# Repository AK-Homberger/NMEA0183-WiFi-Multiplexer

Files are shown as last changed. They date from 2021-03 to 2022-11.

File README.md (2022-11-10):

# NMEA0183 WiFi Multiplexer with ESP8266 (D1 Mini)

# Caution! 
# ----------------------------
This is an updated version (0.2) with pins changed from D7/D8 to D6/D7 to avoid boot problems (see Issues).
If you ordered already a version 1.0 PCB, then just cut the connection to D8 (e.g. with a knife) and solder a wire to D6 pin on D1 Mini. The updated software (version 0.2) will work then. But with changed serial line numbers from #1 to #2 and vice versa.
# ----------------------------

The project reads NMEA0183 messages from two serial (RS232) inputs and forwards multiplexed messages to USB-Serial and WLAN as UDP broadcast.

The multiplexer is powered either from USB connection or with 12 Volt via DC-DC converter.
ESP8266 is using Software Serial on ports D6 and D7.

Main purpose is to provide GPS and AIS information wirelessly to a tablet/smartphone for navigation.
Works with Navionics app (configure UDP connection with Host: x.y.z.255 and Port: 4444).

There is also a [software version](https://github.com/AK-Homberger/NMEA0183-WiFi-Multiplexer/tree/main/NMEA083-Parser-WiFi-Multiplexer) that is parsing the messages and can suppress certain messages. This version needs this additional NMEA0183 libray: https://github.com/ttlappalainen/NMEA0183

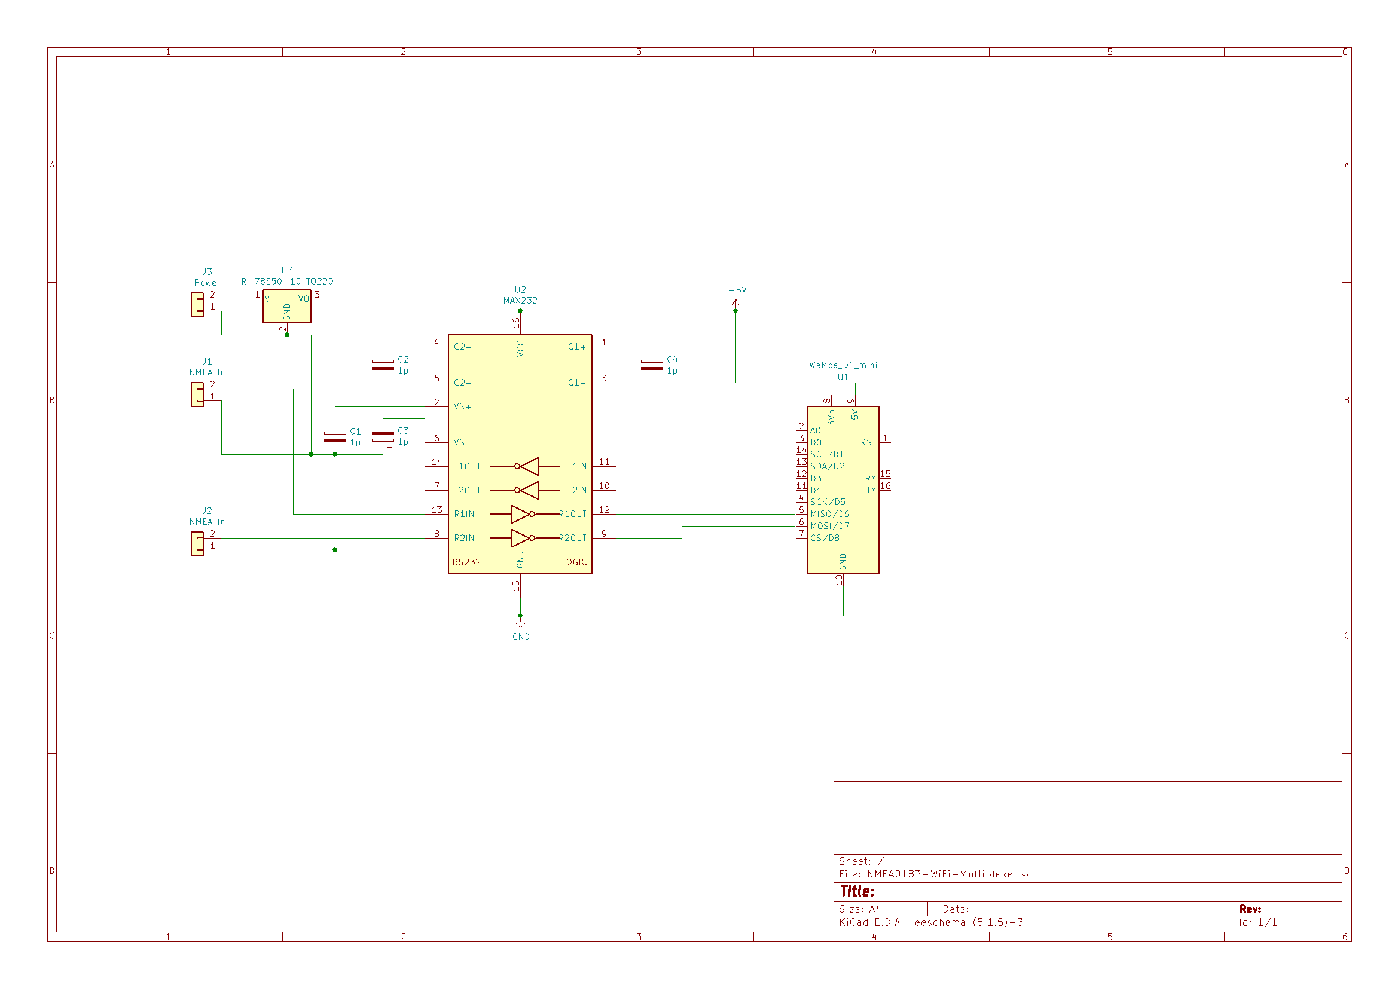
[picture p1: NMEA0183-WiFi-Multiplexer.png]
Schematics


Just change the settings in the [programm](https://github.com/AK-Homberger/NMEA0183-WiFi-Multiplexer/blob/main/NMEA083-WiFi-Multiplexer/NMEA083-WiFi-Multiplexer.ino) according to your needs:

```
// Change these values only
// ------------------------------------------------------------------------
#define AP 0             // Set to 1 to act as Access Point, 0 as client 

const char *ssid      = "ssid";           // Set WLAN name
const char *password  = "password";      // Set password

const char *udpAddress = "192.168.4.255"; // Set network address for broadcast
const int udpPort = 4444;                 // UDP port

#define BaudRate1 4800   // Baud rate for serial#1
#define BaudRate2 38400  // Baud rate for serial#2

// -------------------------------------------------------------------------

```

KiCad files are available to change/extend and to create a [PCB](https://github.com/AK-Homberger/NMEA0183-WiFi-Multiplexer/blob/main/KiCadNMEA0183-WiFi-Multiplexer/PCB.pdf).

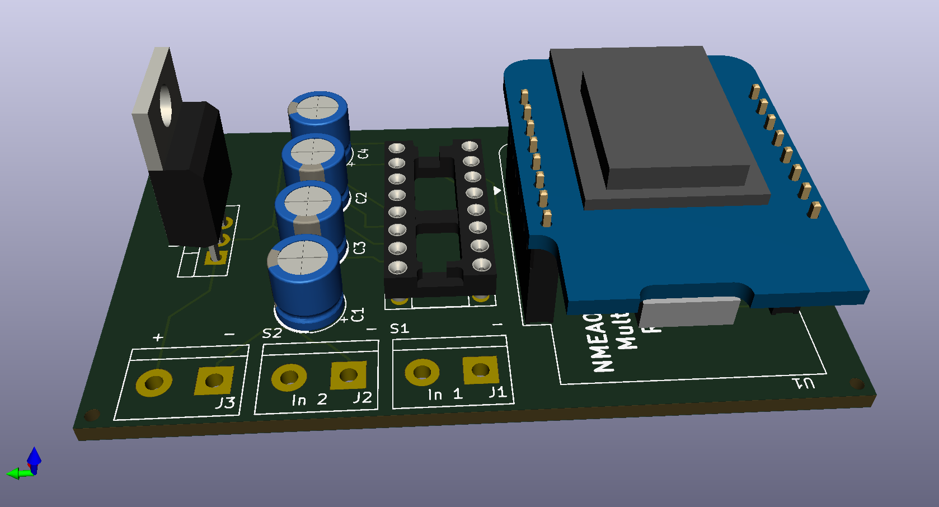
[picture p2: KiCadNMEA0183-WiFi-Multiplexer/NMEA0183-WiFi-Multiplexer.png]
Board


## Parts

- U1: [ESP8266 (D1Mini)](https://www.reichelt.de/de/en/d1-mini-esp8266-v3-0-d1-mini-p253978.html?&nbc=1)
- U2: [Max232](https://www.reichelt.de/de/en/rs232-driver-dil-16-max-232-cpe-p11216.html?&nbc=1)
- C1-C4: 4* [Capacitor 1µF](https://www.reichelt.de/de/en/tantalum-capacitor-rm-2-5-1-0-f-35-v-tantal-1-0-35-p20330.html?&nbc=1)
- J1-J3: 3* [Connector](https://www.reichelt.de/de/en/2-pin-terminal-strip-spacing-5-08-akl-101-02-p36605.html?&nbc=1)
- U3: [DC-DC Converter](https://www.reichelt.de/de/en/dc-dc-converter-5-v-1-a-single-r-78e50-10-p177268.html?&nbc=1)
- [Board](https://aisler.net/p/EZUNBBJG) @Aisler.net

## Updates
- 10.11.2022 - Version 0.3: Corrected line end handling to avaid duplication of messages sent (see Issues).
- 01.10.2021 - Version 0.2: Changed pins from D/D8 to D6/D7 to avoid boot problems (see Issues).
- 06.03.2021 - Version 0.1: Initial version

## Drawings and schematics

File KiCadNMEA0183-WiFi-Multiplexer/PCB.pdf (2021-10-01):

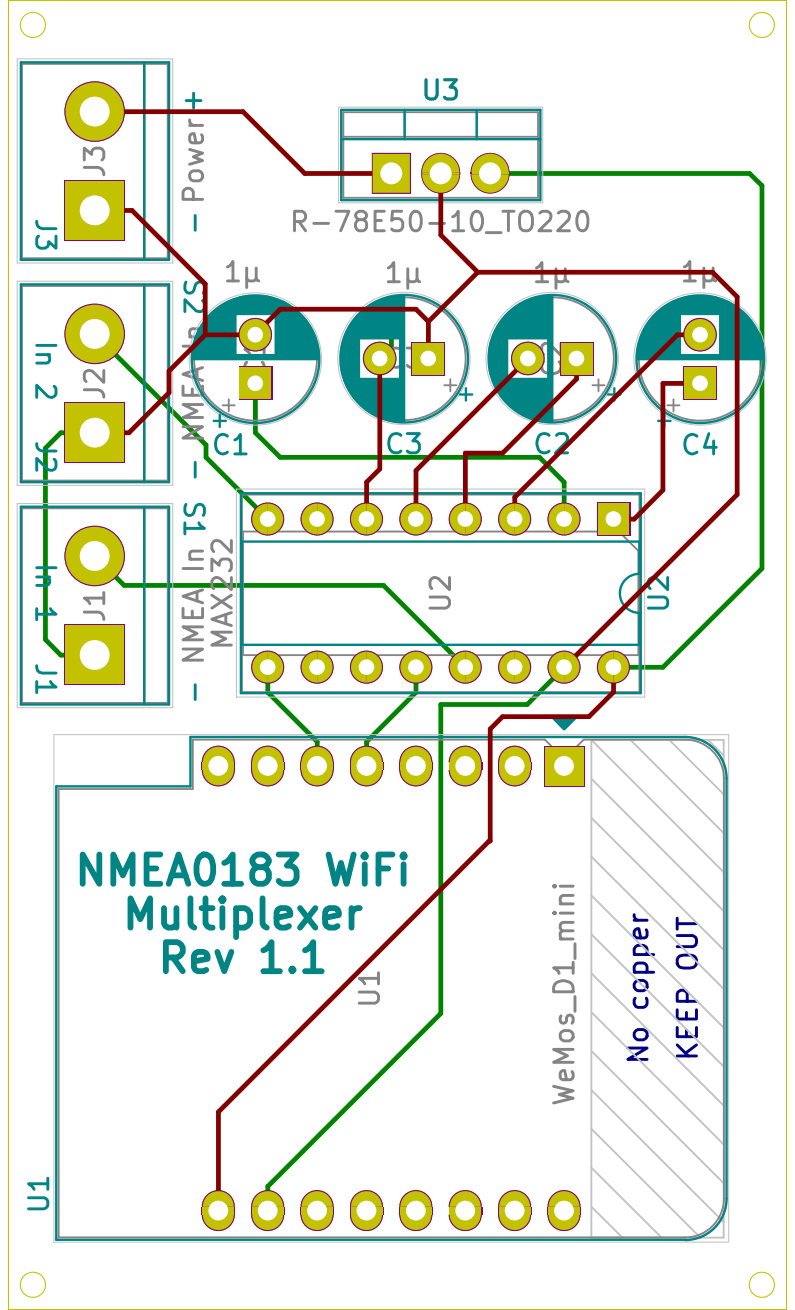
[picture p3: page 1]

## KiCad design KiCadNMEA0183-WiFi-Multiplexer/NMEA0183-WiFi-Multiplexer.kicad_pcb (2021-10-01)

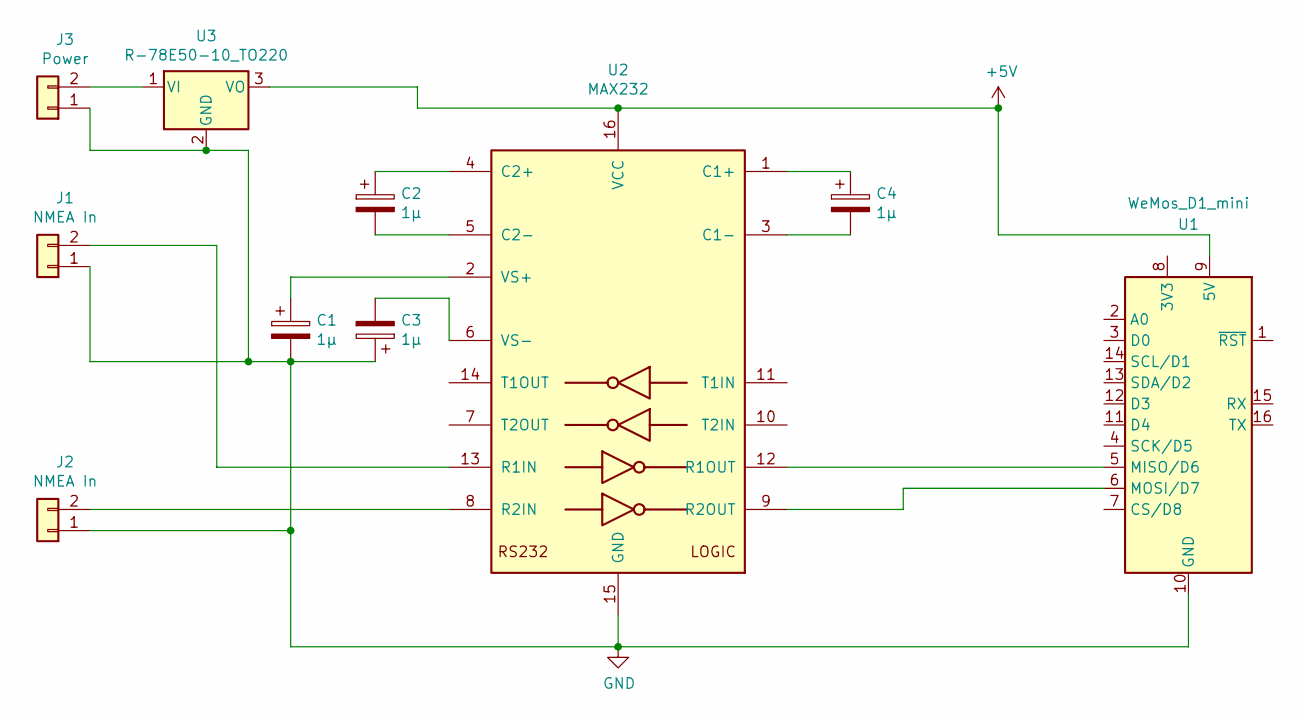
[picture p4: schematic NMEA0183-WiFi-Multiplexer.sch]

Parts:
C1, C2, C3, C4: 1µ; CP_Radial_D6.3mm_P2.50mm
J1, J2: NMEA In; TerminalBlock_bornier-2_P5.08mm
J3: Power; TerminalBlock_bornier-2_P5.08mm
U1: WeMos_D1_mini; WEMOS_D1_mini_light
U2: MAX232; DIP-16_W7.62mm_Socket
U3: R-78E50-10_TO220; TO-220-3_Vertical

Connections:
+5V: U1.9 (5V), U2.16 (VCC), U3.3 (VO)
GND: C1.2, C3.1, J1.1, J2.1, J3.1, U1.10 (GND), U2.15 (GND), U3.2 (GND)
unnamed: C1.1, U2.2 (VS+)
unnamed: C2.1, U2.4 (C2+)
unnamed: C2.2, U2.5 (C2-)
unnamed: C3.2, U2.6 (VS-)
unnamed: C4.1, U2.1 (C1+)
unnamed: C4.2, U2.3 (C1-)
unnamed: J1.2, U2.13 (R1IN)
unnamed: J2.2, U2.8 (R2IN)
unnamed: J3.2, U3.1 (VI)
unnamed: U1.5 (MISO/D6), U2.12 (R1OUT)
unnamed: U1.6 (MOSI/D7), U2.9 (R2OUT)

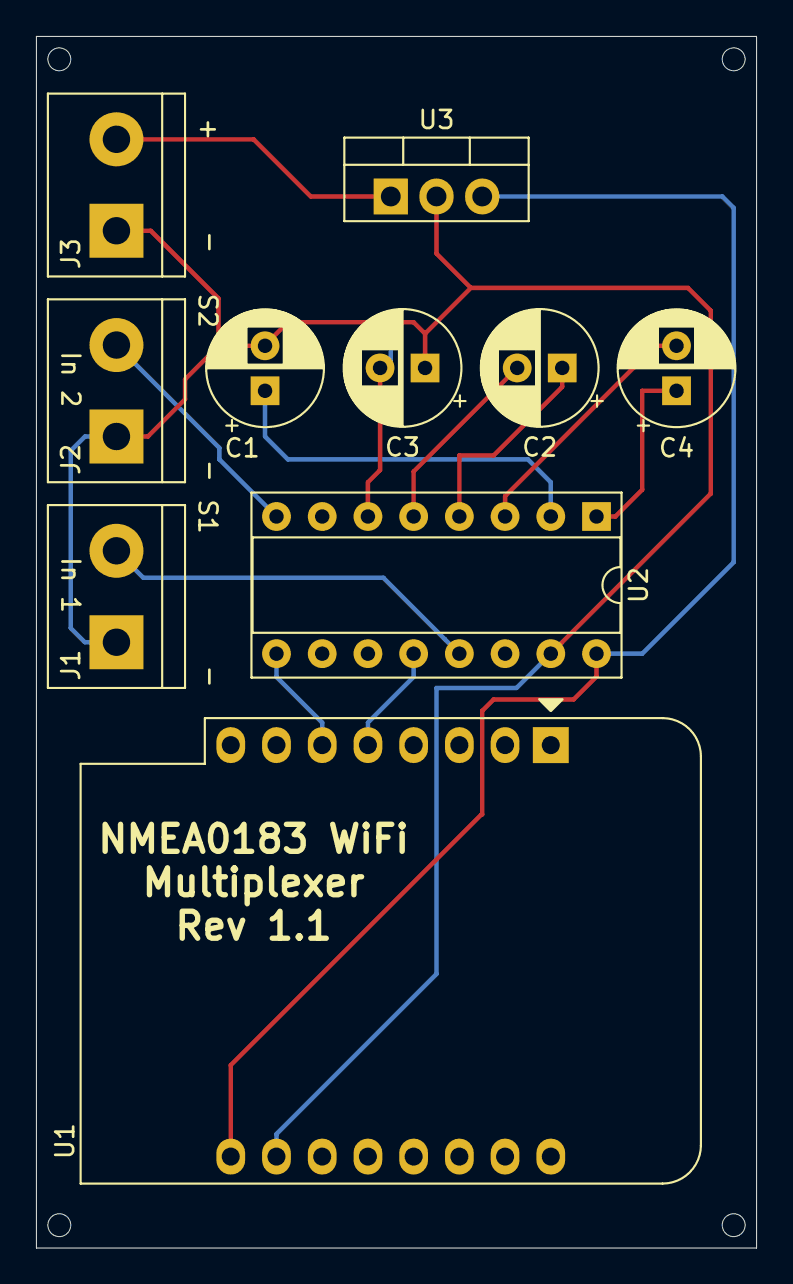
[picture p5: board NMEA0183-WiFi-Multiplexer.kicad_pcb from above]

Board: 2 copper layers, 40.0 x 67.3 mm, 10 parts (0 on the bottom side), 13 nets.

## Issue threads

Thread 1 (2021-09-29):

D8 sets boot loader into programming mode

hinnerkweiler, 2021-09-29:
Hi,

I just finished reconstructing this. However, after some testing I only get it to work when I leave D8 physically disconnected. The Levelshifter seems to send HIGH as soon as the PCB receives power and causes the booting ESP to head straight into Programming mode. Console says: "waiting for host", and that's forever.

I found this for a possible reason:
```
Bootloader Modes

The bootloader can go into a number of modes depending on the state of GPIOs 0, 2 and 15. The two useful modes are the UART download mode (for flashing new firmware) and the flash startup mode (which boots from flash).
						GPIO0(D3) | GPIO2(D4) | GPIO15(D8)
UART Download Mode (Programming)			0 	1 	0
Flash Startup (Normal)					1 	1 	0
SD-Card Boot						0 	0 	1
```

Did you manage to work around this to get the 2nd port activated?

Apparently it seems not to happen using a D1-Mini-Pro (I have none at hand to verify) However on regular D1-Mini (exactly the one you liked to) others also have run into similar problems and reproduced the issue:
https://forum.fhem.de/index.php?topic=71059.0

Hinnerk

AK-Homberger, 2021-10-01:
Changes done.

hinnerkweiler, 2021-10-01:
Ah, sure, that is the simple solution, it worked, while testing everything without the level shifter... Just hoped for a better solution than cutting tracks on the PCBs and run a wire... Just had three boards delivered and found the issue putting everything together. :-/

AK-Homberger, 2021-10-02:
Hi Hinnerk,

Unfortunately, there is no better solution for the old PCBs. But cutting one wire would have been enough. Just cut D8 line and connect to D6. Then change the pin definitions in the code.

And: This is a free of charge DIY solution. This is not a cmmercial product with all testing done and warranty. And my ability to buy and test the full hardware with the PCB is limited.  But I'm happy to react on identified issues and do the corrections/improvements (as I did here).

The situation would be better if at least a few people would use the PayPal button for donations for new hard/software.
But so far only one person used this opportunity.

Regards,
Andreas

Closed 2021-10-01.

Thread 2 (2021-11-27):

Wi-Fi with nmea 0183 data.

AlksSAV, 2021-11-27:
Great device!
I have an echo sounder that can transmit nmea data over Wi Fi. I want to transmit this data to the Ardupilot autopilot.
Is it possible to make nmea 0183 received over Wi-Fi network mixed with the first RS232 and transmitted to the second RS232?
Or just received nmea 0183 via Wi-Fi transmitted over RS232.

AK-Homberger, 2021-11-28:
With the current PCB this is not directly possible. The serial lines are input only.
But with a few changes in hard and software this would be possible.

AlksSAV, 2021-11-29:
> With the current PCB this is not directly possible. The serial lines are input only.
>
> But with a few changes in hard and software this would be possible.

It would be great to get this opportunity. For device tests, you can do without a PCB. If possible, please do the software part.

AK-Homberger, 2021-11-29:
Currently I don't have the time to do this. But I would suggest that you try to do this by your own. Intead of reading from Serial you have to read from a TCP connection and write the message to Serial. Information on how to use TCP is available here: https://github.com/esp8266/Arduino/blob/master/libraries/ESP8266WiFi/examples/WiFiClient/WiFiClient.ino

Closed 2021-12-01.

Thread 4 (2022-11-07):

all nmea data is sent twice

maxnae, 2022-11-07:
Regardless of whether I switch off a softserial or not. all nmea data is sent twice. Can this be prevented?

AK-Homberger, 2022-11-07:
Try to commet out the second send code and check if its now sent only once.

/*
if (GetNMEA0183Message2() == true) {    // Get NMEA sentences from serial#2
    SendNMEA0183Message(buf2);    // Send to clients
  }
*/

And check that there is no shortcut between both serial RX lines.

maxnae, 2022-11-07:
Thanks.
I tried but unfortunately the result is the same. There is also no connection at D6 and D7.

$GPGSV,1,1,00*79
$GPGSV,1,1,00*79
$GLGSV,1,1,00*65
$GLGSV,1,1,00*65
$GNGLL,,,,,,V,N*7A
$GNGLL,,,,,,V,N*7A
$GNRMC,,V,,,,,,,,,,N*4D
$GNRMC,,V,,,,,,,,,,N*4D
$GNVTG,,,,,,,,,N*2E
$GNVTG,,,,,,,,,N*2E
$GNGGA,,,,,,0,00,99.99,,,,,,*56
$GNGGA,,,,,,0,00,99.99,,,,,,*56
$GNGSA,A,1,,,,,,,,,,,,,99.99,99.99,99.99*2E
$GNGSA,A,1,,,,,,,,,,,,,99.99,99.99,99.99*2E
$GNGSA,A,1,,,,,,,,,,,,,99.99,99.99,99.99*2E
$GNGSA,A,1,,,,,,,,,,,,,99.99,99.99,99.99*2E
$GPGSV,1,1,00*79
$GPGSV,1,1,00*79
$GLGSV,1,1,00*65
$GLGSV,1,1,00*65
$GNGLL,,,,,,V,N*7A
$GNGLL,,,,,,V,N*7A
is it maybe necessary to have a delay when reading softserial?
best regards max

maxnae, 2022-11-09:
Here is the output

68
13
$GNRMC,,V,,,,,,,,,,N*4D
10
$GNRMC,,V,,,,,,,,,,N*4D
36
71
78
86
84
71
44
44
44
44
44
44
44
44
44
78
42
50
69
13
$GNVTG,,,,,,,,,N*2E
10
$GNVTG,,,,,,,,,N*2E
36
71
78
71
71
65
44
44
44
44
44
44
48
44
48
48
44
57
57
46
57
57
44
44
44
44
44
44
42
53
54
13
$GNGGA,,,,,,0,00,99.99,,,,,,*56
10
$GNGGA,,,,,,0,00,99.99,,,,,,*56
36
71
78
71
83
65
44
65
44
49
44
44
44
44
44
44
44
44
44
44
44
44
44
57
57
46
57
57
44
57
57
46
57
57
44
57
57
46
57
57
42
50
69
13
$GNGSA,A,1,,,,,,,,,,,,,99.99,99.99,99.99*2E
10
$GNGSA,A,1,,,,,,,,,,,,,99.99,99.99,99.99*2E
36
71
78
71
83
65
44
65
best regards max

AK-Homberger, 2022-11-09:
Each caracter is received only once. That's OK so far. But then the buffer is sent twice. One time after CR (\n) and another time after receiving LF (\r). But that should not happen.

Please add these both lines in both receive functions:

if(ReceivedChars == 0 && (Char == '\r')) return false;
if(ReceivedChars == 0 && (Char == '\n')) return false;

before this code:

if ( (Char == '\n') || (Char == '\r') ) {
      ReceivedChars = 0;
      return true;
    }

Then it should work. It looks like my test system only sent one of the line end codes.

maxnae, 2022-11-09:
wonderful thanks worked.

one more question, how can I filter different gps sets so that they are not sent further or specify which ones to go through?

$GNVTG
$GPGSV
$GLGSV

best regards max

AK-Homberger, 2022-11-10:
You have to parse the NME0183 messages. You can try to use this library https://github.com/ttlappalainen/NMEA0183). But I think it's not directly working with SoftwareSerial.

maxnae, 2022-11-10:
Thank you very much, it looks like this is working perfectly.
I modified that a bit. looks awesome

  // Receive and check message codes to suppress
  if (NMEA0183_1.GetMessage(NMEA0183Msg)) {    // Get NMEA sentences from serial#1

    if (!((strcmp(NMEA0183Msg.Sender(), "GP") == 0) && NMEA0183Msg.IsMessageCode("GSV") ||
          (strcmp(NMEA0183Msg.Sender(), "GN") == 0) && NMEA0183Msg.IsMessageCode("VTG") ||
          (strcmp(NMEA0183Msg.Sender(), "GN") == 0) && NMEA0183Msg.IsMessageCode("GLL") ||
          (strcmp(NMEA0183Msg.Sender(), "GL") == 0) && NMEA0183Msg.IsMessageCode("GSV"))) {

      if (NMEA0183Msg.GetMessage(buf, MAX_NMEA0183_MESSAGE_SIZE - 1)) {
         SendNMEA0183Message(buf);    // Send to clients

best regards max

maxnae, 2022-11-11:
another question. I'm currently trying to transmit Softserial 1 filtered and Softserial2 as RAW (is not an NMEA sentence). Unfortunately I seem to have made a mistake here.
[NMEA083-Parser-WiFiMultiplexer_mod.txt](https://github.com/AK-Homberger/NMEA0183-WiFi-Multiplexer/files/9987979/NMEA083-Parser-WiFiMultiplexer_mod.txt)
best regards max

maxnae, 2022-11-18:
Thank you very much
best regards max

Closed 2022-11-18.

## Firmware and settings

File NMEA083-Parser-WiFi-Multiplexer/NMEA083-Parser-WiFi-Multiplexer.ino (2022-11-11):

/*
  This code is free software; you can redistribute it and/or
  modify it under the terms of the GNU Lesser General Public
  License as published by the Free Software Foundation; either
  version 2.1 of the License, or (at your option) any later version.
  This code is distributed in the hope that it will be useful,
  but WITHOUT ANY WARRANTY; without even the implied warranty of
  MERCHANTABILITY or FITNESS FOR A PARTICULAR PURPOSE.  See the GNU
  Lesser General Public License for more details.
  You should have received a copy of the GNU Lesser General Public
  License along with this library; if not, write to the Free Software
  Foundation, Inc., 51 Franklin St, Fifth Floor, Boston, MA  02110-1301  USA
*/
// NMEA0183 WiFi Multiplexer with NME0183 Message Parser to suppress or parse certain messages

// Reads NMEA0183 messages from serial connected to D6 and D7.
// Forwards multiplexed messages to USB-Serial and WLAN as UDP broadcast.
// Needs this NMEA0183 libray: https://github.com/ttlappalainen/NMEA0183

// Version 0.1, 10.11.2022, AK-Homberger

#include <ESP8266WiFi.h>
#include <WiFiUdp.h>
#include <SoftwareSerial.h>
#include <NMEA0183.h>
#include <NMEA0183Messages.h>

// Change these values only
// ------------------------------------------------------------------------
#define AP 1             // Set to 1 to act as Access Point, 0 as client 

const char *ssid      = "ssid";           // Set WLAN name
const char *password  = "password";       // Set password

const char *udpAddress = "192.168.4.255"; // Set network address for broadcast
const int udpPort = 4444;                 // UDP port

#define BaudRate1 4800   // Baud rate for serial#1
#define BaudRate2 4800   // Baud rate for serial#2

// -------------------------------------------------------------------------


#define MAX_NMEA0183_MESSAGE_SIZE 150
char buf[MAX_NMEA0183_MESSAGE_SIZE] = "";  // Buffer for message to send

// Create software serial objects
SoftwareSerial swSer1;
SoftwareSerial swSer2;

// NMEA streams for NMEA0183 receiving
tNMEA0183 NMEA0183_1;
tNMEA0183 NMEA0183_2;

boolean wifiConnected = false;

// Create UDP instance
WiFiUDP udp;


//*****************************************************************************
void setup(void) {

  Serial.begin(115200);

  // Initialise wifi connection
  wifiConnected = connectWifi();            // Connect to WLAN or start AP

  if (!wifiConnected) {
    Serial.println("Cannot connect to WiFi. Please check data. Reset the ESP now.");
    delay(3000);
    ESP.restart();
  }

  // Initialise software serial set baud rate to 4800 or 38400
  swSer1.begin(BaudRate1, SWSERIAL_8N1, D6, D6, false, 256);
  swSer1.enableIntTx(false);
  NMEA0183_1.SetMessageStream(&swSer1, 1);
  NMEA0183_1.Open();

  swSer2.begin(BaudRate2, SWSERIAL_8N1, D7, D7, false, 256);
  swSer2.enableIntTx(false);
  NMEA0183_2.SetMessageStream(&swSer2, 2);
  NMEA0183_2.Open();
}


//*****************************************************************************
// Connect to wifi or start AP – returns true if successful or false if not

boolean connectWifi() {
  boolean state = true;
  int i = 0;

  if (AP == 0) {
    WiFi.mode(WIFI_STA);
    WiFi.hostname("NMEA0183Multiplexer");
    WiFi.begin(ssid, password);
    Serial.println("Connecting to WiFi");
    // Wait for connection
    Serial.print("Connecting...");
    // Initialise wifi connection

    while (WiFi.status() != WL_CONNECTED) {
      delay(500);
      Serial.print(".");
      if (i > 10) {
        state = false; break;
      }
      i++;
    }
    Serial.println("");
    if (state) {
      Serial.print("Connected to ");
      Serial.println(ssid);
      Serial.print("IP address: ");
      Serial.println(WiFi.localIP());
    }
    else {
      Serial.println("Connection failed.");
    }
    return state;
  }  else {

    Serial.println("Start WLAN AP");         // WiFi Mode AP
    WiFi.mode(WIFI_AP);
    WiFi.softAP(ssid, password);
    delay(100);
    IPAddress IP = WiFi.softAPIP();
    Serial.println("");
    Serial.print("AP IP address: ");
    Serial.println(IP);
    return true;
  }
}


//*****************************************************************************
// Check WiFi connection

void Check_WiFi(void) {
  boolean wifiConnected = false;

  if (AP != 0) return;   // We are acting as AP. Connection check not necessary

  if (WiFi.status() != WL_CONNECTED) { // Wifi restart
    WiFi.disconnect();
    WiFi.mode(WIFI_OFF);
    WiFi.mode(WIFI_STA);

    Serial.println("Reconnect!");
    wifiConnected = connectWifi();

    if (!wifiConnected) {
      Serial.println("Cannot connect to WiFi. Please check data. Reset the ESP now.");
      delay(2500);
      ESP.restart();
    }
  }
}


//*****************************************************************************
void SendNMEA0183Message(char *buf) {

  udp.beginPacket(udpAddress, udpPort);   // Send to UDP
  udp.println(buf);
  udp.endPacket();

  //Serial.println(buf);    // Send to USB-Serial. Uncomment if needed
}


//*****************************************************************************
void HandleMWV(const tNMEA0183Msg &NMEA0183Msg) {
  double WindAngle;
  tNMEA0183WindReference Reference;
  double WindSpeed;

  // Parse MWV message (WindSpeed is in m/s !!!)
  if (!NMEA0183ParseMWV_nc(NMEA0183Msg, WindAngle, Reference, WindSpeed)) return;

  Serial.printf("Angle=%4.1f°, Speeed=%3.1f kn \n", WindAngle, WindSpeed*3600L/1852.0L);
}


//*****************************************************************************
void loop(void) {
  tNMEA0183Msg NMEA0183Msg;  // Create message container

  Check_WiFi();

  // Receive and check message codes to suppress
  if (NMEA0183_1.GetMessage(NMEA0183Msg)) {    // Get NMEA sentences from serial#1

    if (!((strcmp(NMEA0183Msg.Sender(), "GP") == 0) && NMEA0183Msg.IsMessageCode("GSV") ||
          (strcmp(NMEA0183Msg.Sender(), "GL") == 0) && NMEA0183Msg.IsMessageCode("GSV"))) {

      if (NMEA0183Msg.GetMessage(buf, MAX_NMEA0183_MESSAGE_SIZE - 1)) {
        SendNMEA0183Message(buf);    // Send to clients
      }
    }
  }

  // Receive and send without modification. And parse/display wind information (MWV)
  if (NMEA0183_2.GetMessage(NMEA0183Msg)) {    // Get NMEA sentences from serial#2
    if (NMEA0183Msg.GetMessage(buf, MAX_NMEA0183_MESSAGE_SIZE - 1)) {
      SendNMEA0183Message(buf);    // Send to clients
    }
  if (NMEA0183Msg.IsMessageCode("MWV")) HandleMWV(NMEA0183Msg);  // Check and handle message 
  }
}

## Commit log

2021-10-01 Changed to D6/D7 input pins to avoid boot problems (see Issues)
    [NMEA083-WiFi-Multiplexer.ino]
2021-10-01 Version 1.1 (Changed to D7/D2 pins to avoid boot problems).
    [NMEA0183-WiFi-Multiplexer.kicad_pcb, NMEA0183-WiFi-Multiplexer.sch]
2022-11-10 Corrected line end handling.
    [NMEA083-WiFi-Multiplexer.ino]
